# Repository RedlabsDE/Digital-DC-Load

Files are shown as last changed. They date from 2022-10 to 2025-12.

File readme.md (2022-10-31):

# Digtial DC Load Project

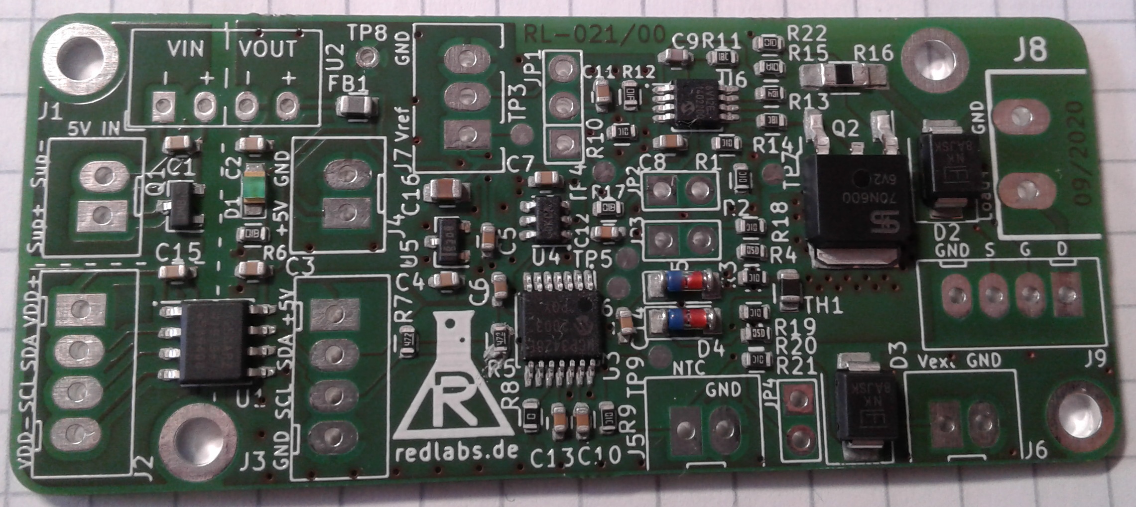
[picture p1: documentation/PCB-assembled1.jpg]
PCB assembled


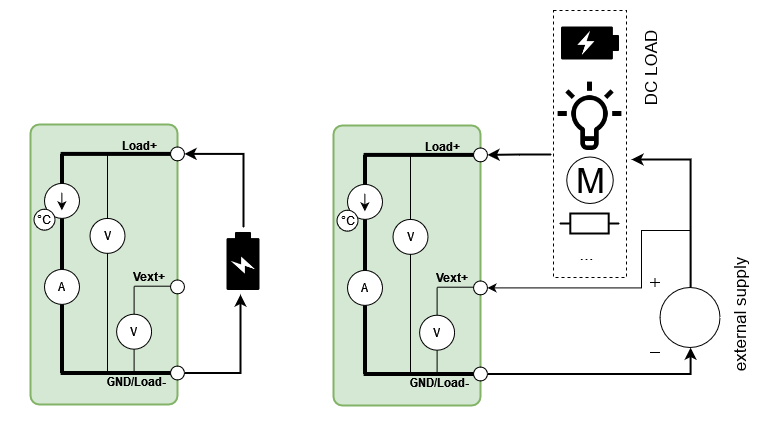
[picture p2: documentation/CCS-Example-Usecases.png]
Blockdiagram of example usecases Example Usecases


**key features:**
- linear constant curren sink
- galvanic isolated
- selectable operating range (high/low current/voltage)
- controlled via I2C
	- write & read load current
	- read load voltage
	- read additional external voltage
	- read temperature 
- manual option: set current via external voltage (or potentiometer)

**example application:**
- charge / discharge battery (control & measure current and voltage)
- measure & log current/voltage (use example setup to send data to PC)
- stess test of power supply

## Repository Overview
- **documentation**
  - application notes for constant current sink 
  - block diagram of PCB
  - screenshots and pictures of this project
- **firmware**
  - Arduino Example Project `DigitalLoadExample`, inlcuding a C++ class `RL021_DigitalLoad` for easy control
  - Example calibration procedure (manually step by step)
- **hardware**
  - **KiCAD** Project Folder including schematic, PCB layout and BOM
  - **schematic** and fabrication layer drawing as PDF
  - **datasheet** of used components
- **ui**
  - **GUI_CSS** is an example project for a simple pc-based user interface (written in processing)

## Hardware
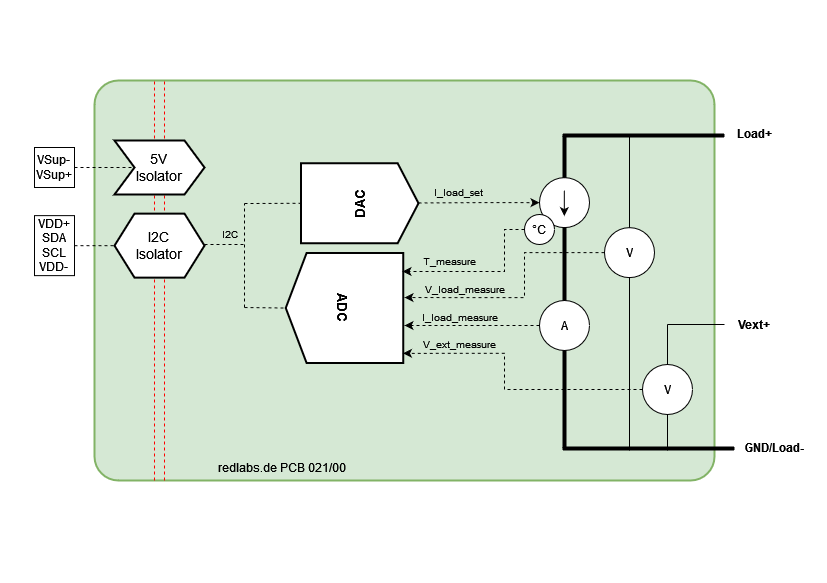
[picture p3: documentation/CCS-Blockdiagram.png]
Blockdiagram of PCB Blockdiagram

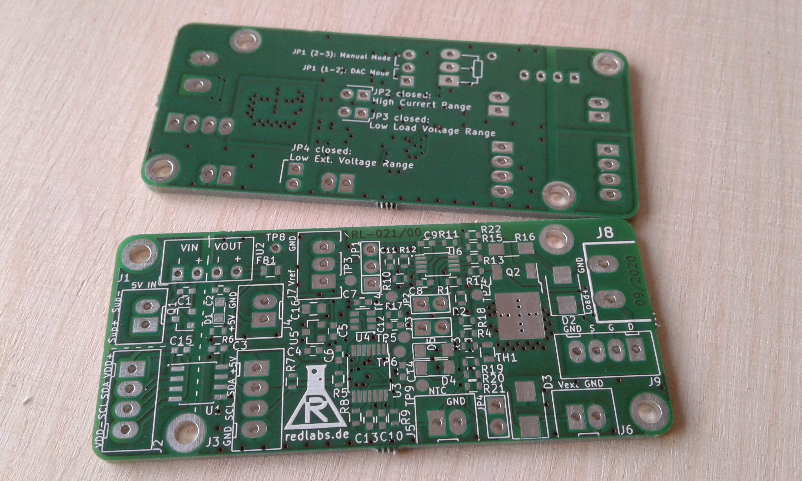
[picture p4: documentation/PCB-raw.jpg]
PCB not assembled


**Order PCB:** https://aisler.net/p/YHESFYKF

### Jumper Settings
Via multiple jumpers the used operating ranges can be configured.

| Parameter | Jumper | open | closed |
| -- | -- | -- | -- |
| Current Control | JP1 | External analog signal | Digital via onboard DAC |
| I_load range | JP2 | low 0-1A | high 0-10A |
| V_load range | JP3 | high 0-24V | 0-4V |
| V_extern range | JP4 | high 0-24V | 0-4V |
| ADC I2C Addr (A2,A1,A0)| R8 | 0,0,1 | 0,0,0 |

# Example Setup
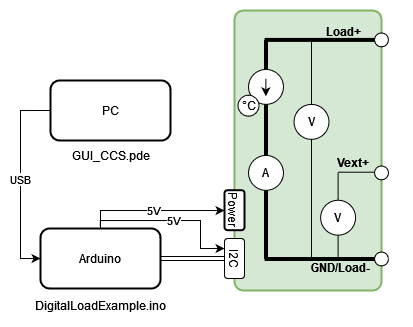
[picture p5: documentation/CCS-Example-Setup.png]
Blockdiagram of example setup Example Setup


## Example Arduino Control

### Connect Arduino to CCS-PCB
| Signal 	| Arduino Pin |
|---|---|
| I2C_VDD (J2, pin1) 	| 5V 	|
| I2C_SDA (J2, pin2) 		| A4 |
| I2C_SCL (J2, pin3) 	| A5 	|
| I2C_GND (J2, pin4) 	| GND 	|
| SUPPLY_+5V (J1, pin1) 	| 5V 	|
| SUPPLY_GND (J1, pin2) 	| GND 	|

### Configure CCS-PCB according to your application
- See chapter "Jumper Settings" to select your operating range
- In the Arduino Code, the settings should be set according to physical state of the jumpers:
	```
		/// Write board jumper settings (like set on PCB)
		myLoad.SetJumperSetting(JP2_CURRENT,Jumper_Closed);
		myLoad.SetJumperSetting(JP3_VLOAD,Jumper_Open);
		myLoad.SetJumperSetting(JP4_VEXT,Jumper_Open);  
	```

## Example User Interface
An example PC-based user interface (written in "Processing"), for the use with the `firmware/DigitalLoadExample` project.

### Connect UI to Arduino ###
- The UI communicates via serial comport using simple ASCII character commands, so the communication could also be done manual.  
- The UI uses the first found COMPORT (to use another port, change this in the processing code)
	````
	  String portName = Serial.list()[0];
	  myPort = new Serial(this, portName, 115200);
	````
### Usage ###
In the "Control" page, all measured values are displayed in SI-units. The user can set the desired load current in mA.
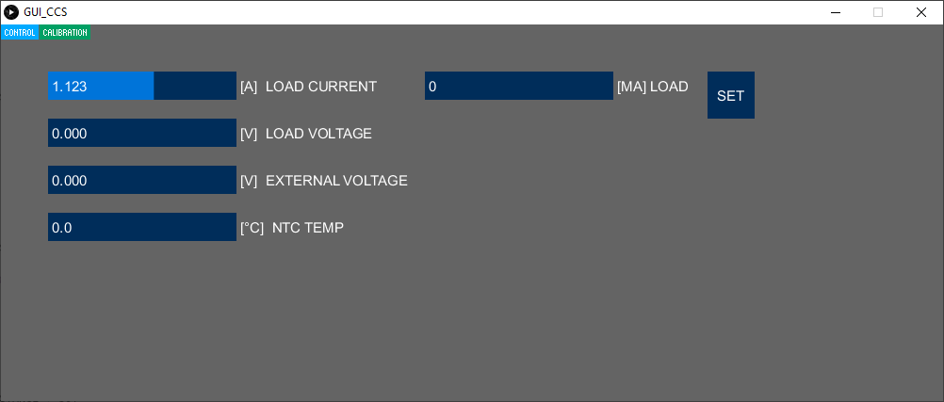
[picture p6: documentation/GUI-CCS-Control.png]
GUI Control


In the "Calibration" page, the raw ADC values are displayed. The user can set the raw DAC value.
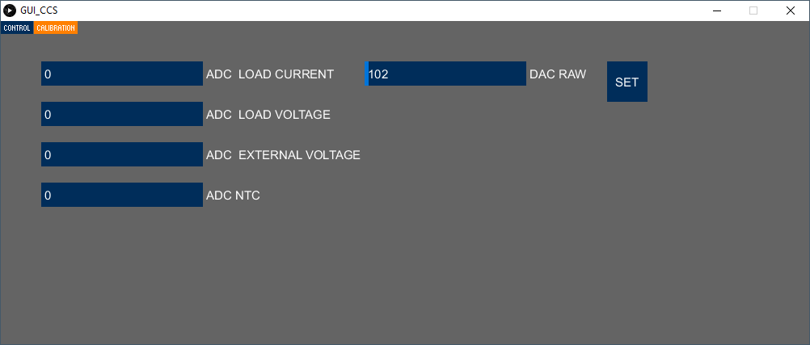
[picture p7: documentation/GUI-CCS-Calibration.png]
GUI Control GUI Calibration


... find other projects: https://redlabs.de/

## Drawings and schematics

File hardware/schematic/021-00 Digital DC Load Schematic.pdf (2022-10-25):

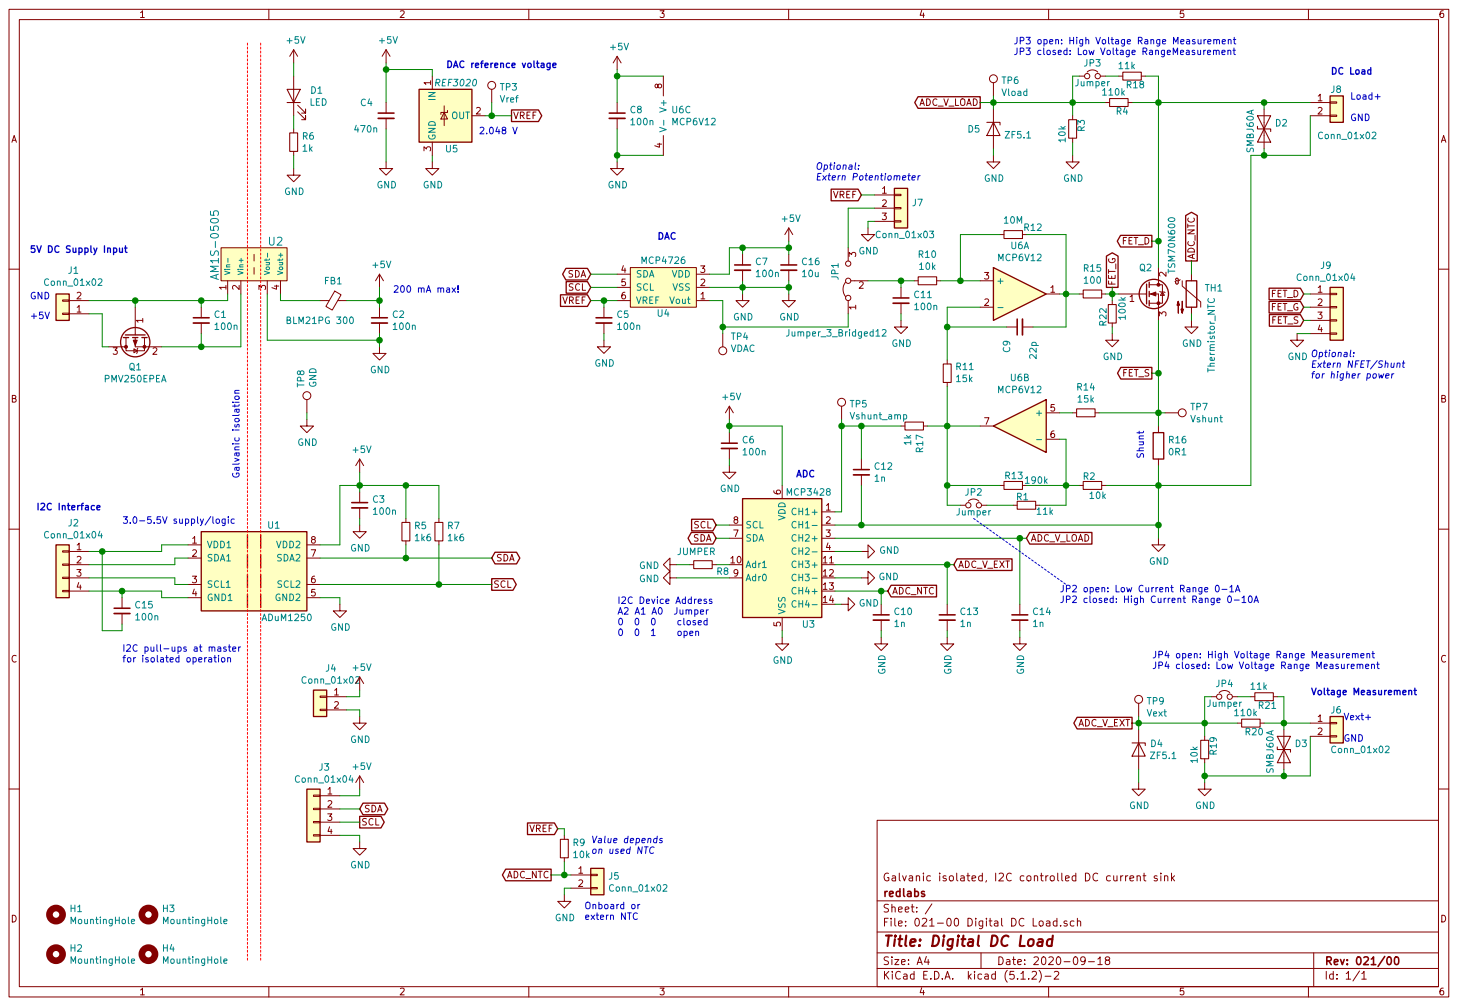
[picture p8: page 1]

JP3 open: High Voltage Range Measurement
JP3 closed: Low Voltage RangeMeasurement
VREF Optional: Extern Potentiometer GND

Optional: Extern NFET/Shunt

JP2 open: Low Current Range 0-1A
1n GND

I2C Device Address A2 A1 A0 Jumper 0 0 0 closed

I2C pull-ups at master
for isolated operation

JP4 open: High Voltage Range Measurement
JP4 closed: Low Voltage Range Measurement
Jumper GND

Value depends on used NTC

Id: 1/1 Title: Digital DC Load

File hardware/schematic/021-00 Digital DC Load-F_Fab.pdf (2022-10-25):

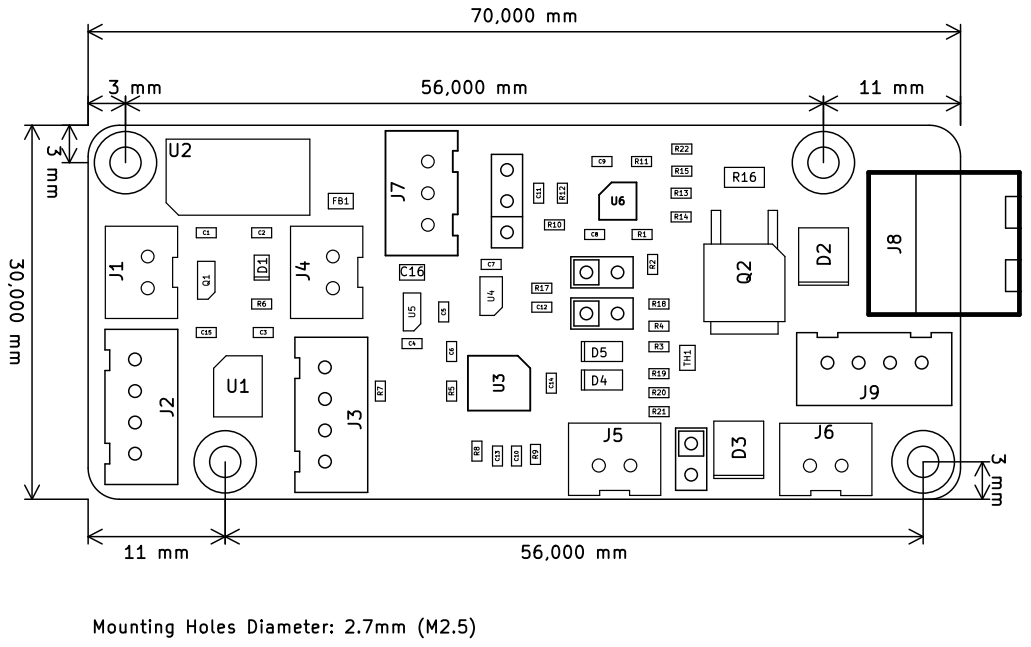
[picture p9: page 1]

File: 021-00 Digital DC Load.kicad_pcb Sheet:
Id: 1/1 Title:

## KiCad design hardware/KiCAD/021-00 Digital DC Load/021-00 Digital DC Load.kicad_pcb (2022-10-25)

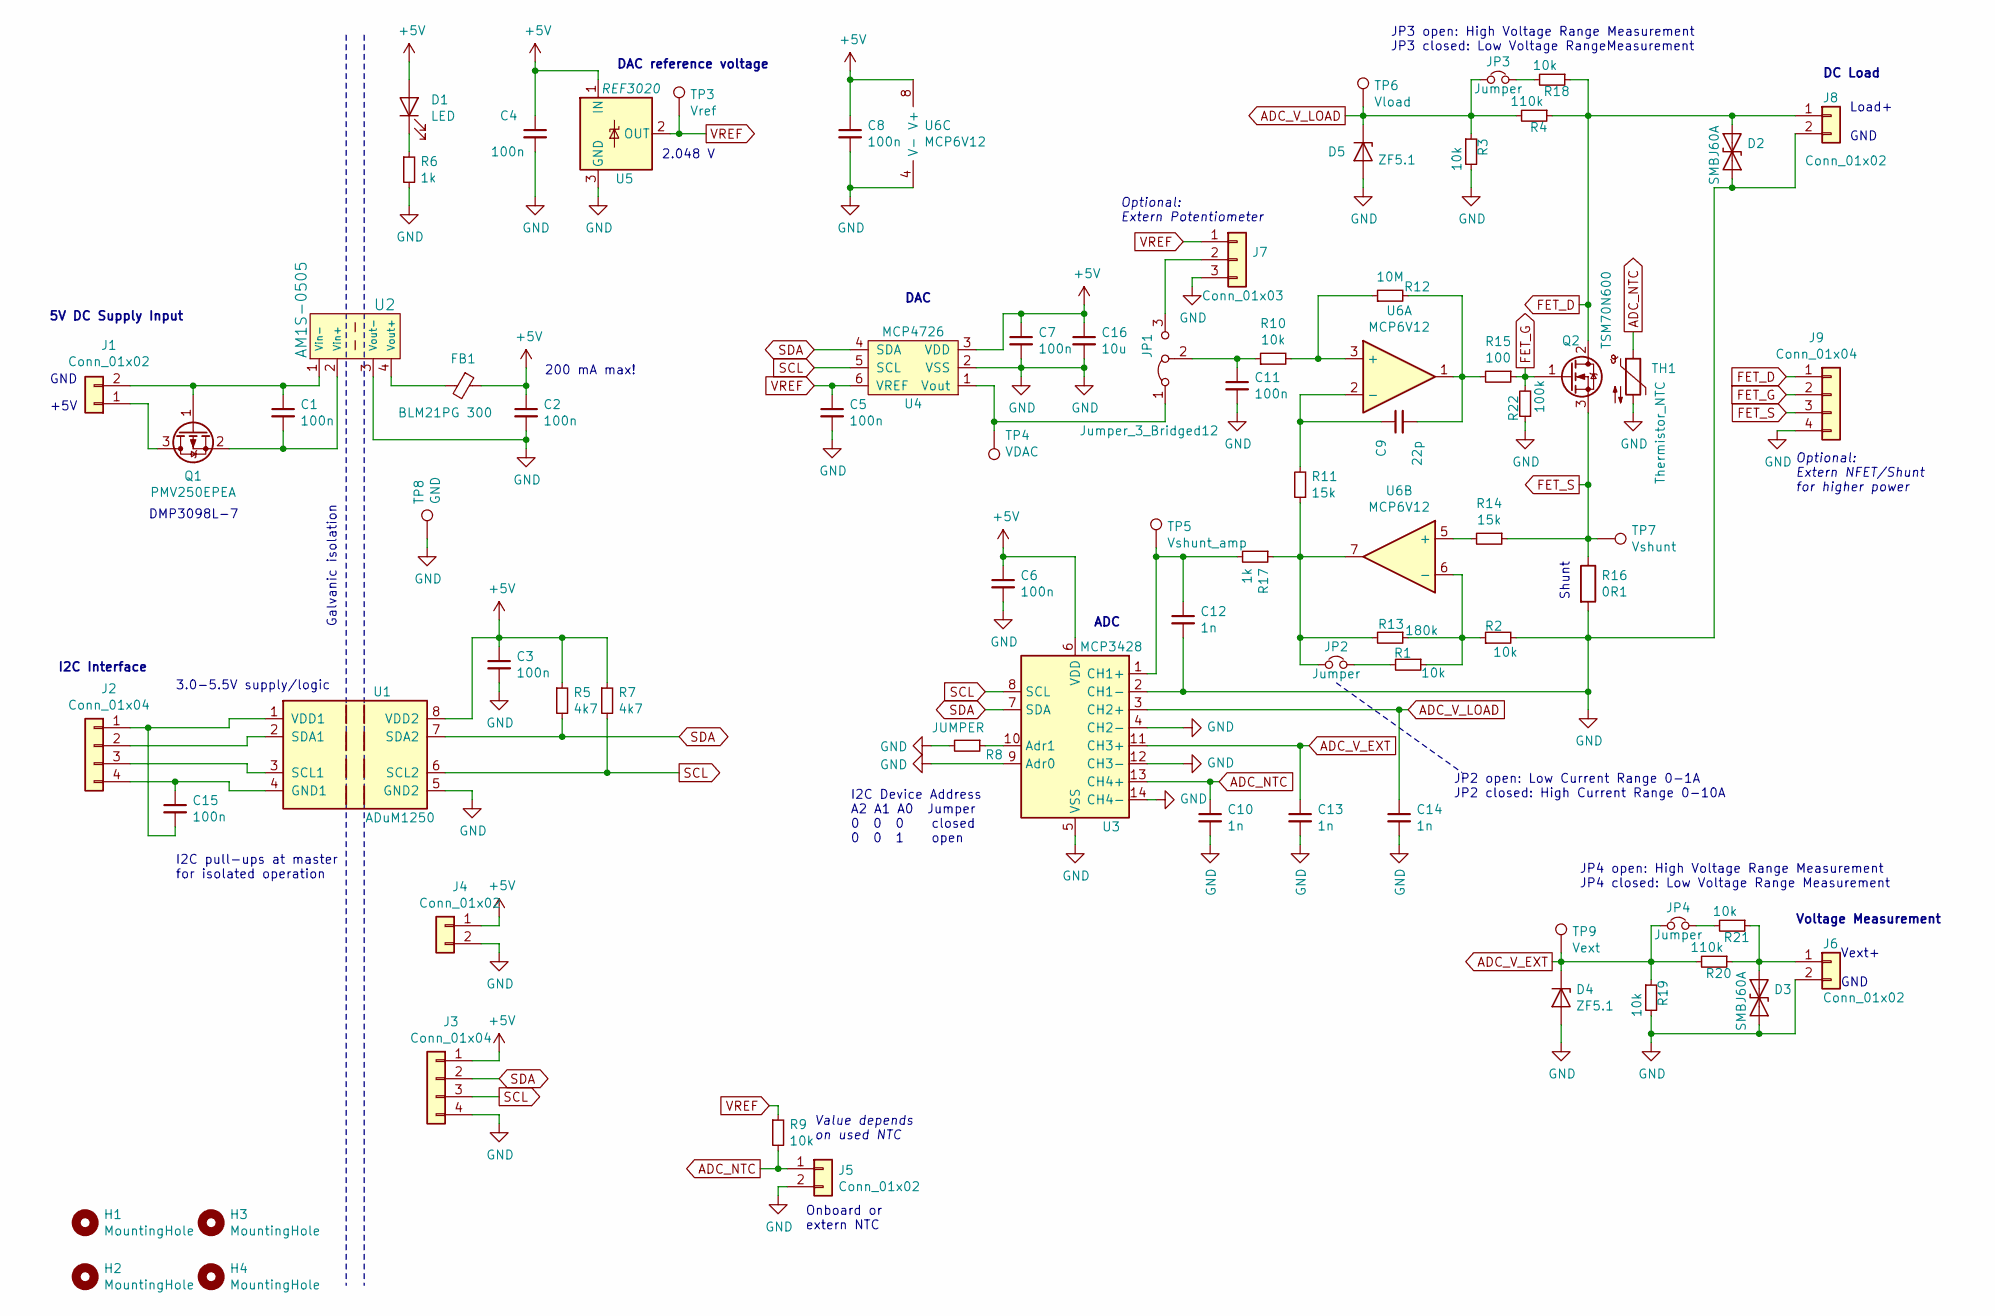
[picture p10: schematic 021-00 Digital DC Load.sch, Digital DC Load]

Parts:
C1, C2, C3, C4, C5, C6, C7, C8, C11, C15: 100n; C_0603
C9: 22p; C_0603
C10, C12, C13, C14: 1n; C_0603
C16: 10u; C_0805
D1: LED; LED_0805
D2, D3: SMBJ60A; D_SMB_bidirectional
D4, D5: ZF5.1; D_MiniMELF
FB1: BLM21PG 300; R_0805
H1, H2, H3, H4: MountingHole; MountingHole_2.7mm_M2.5_DIN965_Pad
J1, J4, J5, J6: Conn_01x02; JST_XH2P_oval_pads
J2, J3, J9: Conn_01x04; JST_XH4P_oval_pads
J7: Conn_01x03; JST_XH3P_oval_pads
J8: Conn_01x02; AKL_2_RM508_RND205-00199
JP1: Jumper_3_Bridged12; PIN_ARRAY_3X1_big_pads
JP2, JP3, JP4: Jumper; PIN_ARRAY_2X1_big_pads
Q1: PMV250EPEA; SOT-23
Q2: TSM70N600; TO-252-2
R1, R2, R3, R9, R10, R18, R19, R21: 10k; R_0603
R4, R20: 110k; R_0603
R5, R7: 4k7; R_0603
R6, R17: 1k; R_0603
R8: JUMPER; R_0603
R11, R14: 15k; R_0603
R12: 10M; R_0603
R13: 180k; R_0603
R15: 100; R_0603
R16: 0R1; R_1206_HandSoldering
R22: 100k; R_0603
TH1: Thermistor_NTC; R_0805
TP3: Vref; Measurement_Point_Round-SMD-Pad_Small
TP4: VDAC; Measurement_Point_Round-SMD-Pad_Small
TP5: Vshunt_amp; Measurement_Point_Round-SMD-Pad_Small
TP6: Vload; Measurement_Point_Round-SMD-Pad_Small
TP7: Vshunt; Measurement_Point_Round-SMD-Pad_Small
TP8: GND; Measurement_Point_Round-TH_Small
TP9: Vext; Measurement_Point_Round-SMD-Pad_Small
U1: ADuM1250; SOIC-8_3.9x4.9mm_Pitch1.27mm
U2: AM1S-0505; DCDC-Isolated-SIP4
U3: MCP3428; TSSOP-14_4.4x5mm_Pitch0.65mm
U4: MCP4726; SOT-23-6
U5: REF3020; SOT-23
U6: MCP6V12; MSOP-8_3x3mm_Pitch0.65mm

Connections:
+5V: C2.1, C3.1, C4.1, C6.1, C7.1, C8.1, C16.1, D1.2 (A), FB1.1, J3.1, J4.1, R5.1, R7.1, U1.8 (VDD2), U3.6 (VDD), U4.3 (VDD), U5.1 (IN), U6.8 (V+)
ADC_NTC: C10.1, J5.1, R9.2, TH1.1, U3.13 (CH4+)
ADC_V_EXT: C13.1, D4.1 (K), JP4.1, R19.1, R20.2, TP9.1, U3.11 (CH3+)
ADC_V_LOAD: C14.1, D5.1 (K), JP3.1, R3.1, R4.2, TP6.1, U3.3 (CH2+)
FET_D: D2.1 (A1), J8.1, J9.1, Q2.2 (D), R4.1, R18.1
FET_G: J9.2, Q2.1 (G), R15.1, R22.2
FET_S: J9.3, Q2.3 (S), R14.1, R16.1, TP7.1
GND: C2.2, C3.2, C4.2, C5.2, C6.2, C7.2, C8.2, C10.2, C11.2, C12.2, C13.2, C14.2, C16.2, D2.2 (A2), D3.2 (A2), D4.2 (A), D5.2 (A), J3.4, J4.2, J5.2, J6.2, J7.3, J8.2, J9.4, R2.2, R3.2, R6.2, R8.2, R16.2, R19.2, R22.1, TH1.2, TP8.1, U1.5 (GND2), U2.3 (Vout-), U3.2 (CH1-), U3.4 (CH2-), U3.5 (VSS), U3.9 (Adr0), U3.12 (CH3-), U3.14 (CH4-), U4.2 (VSS), U5.3 (GND), U6.4 (V-)
unnamed: C1.1, J1.2, Q1.1 (G), U2.1 (Vin-)
unnamed: C1.2, Q1.2 (S), U2.2 (Vin+)
unnamed: C9.1, R11.2, U6.2 (-)
unnamed: C9.2, R12.2, R15.2, U6.1
unnamed: C11.1, JP1.2 (C), R10.1
unnamed: C12.1, R17.2, TP5.1, U3.1 (CH1+)
unnamed: C15.1, J2.4, U1.4 (GND1)
unnamed: C15.2, J2.1, U1.1 (VDD1)
unnamed: D1.1 (K), R6.1
unnamed: D3.1 (A1), J6.1, R20.1, R21.1
unnamed: FB1.2, U2.4 (Vout+)
unnamed: J1.1, Q1.3 (D)
unnamed: J2.2, U1.2 (SDA1)
unnamed: J2.3, U1.3 (SCL1)
unnamed: J7.2, JP1.3 (B)
unnamed: JP1.1 (A), TP4.1, U4.1 (Vout)
unnamed: JP2.1, R11.1, R13.2, R17.1, U6.7
unnamed: JP2.2, R1.2
unnamed: JP3.2, R18.2
unnamed: JP4.2, R21.2
unnamed: R1.1, R2.1, R13.1, U6.6 (-)
unnamed: R8.1, U3.10 (Adr1)
unnamed: R10.2, R12.1, U6.3 (+)
unnamed: R14.2, U6.5 (+)
SCL: J3.3, R7.2, U1.6 (SCL2), U3.8 (SCL), U4.5 (SCL)
SDA: J3.2, R5.2, U1.7 (SDA2), U3.7 (SDA), U4.4 (SDA)
VREF: C5.1, J7.1, R9.1, TP3.1, U4.6 (VREF), U5.2 (OUT)

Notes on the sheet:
2.048 V
I2C Device Address A2 A1 A0 Jumper 0 0 0 closed 0 0 1 open
Shunt
Optional: Extern Potentiometer
Onboard or extern NTC
5V DC Supply Input
I2C Interface
3.0-5.5V supply/logic
I2C pull-ups at master for isolated operation
+5V
GND
200 mA max!
Optional: Extern NFET/Shunt for higher power
Galvanic isolation
DC Load
Value depends on used NTC
DAC
ADC
DAC reference voltage
Load+ GND
Voltage Measurement
Vext+ GND
JP4 open: High Voltage Range Measurement JP4 closed: Low Voltage Range Measurement
JP3 open: High Voltage Range Measurement JP3 closed: Low Voltage RangeMeasurement
JP2 open: Low Current Range 0-1A JP2 closed: High Current Range 0-10A
DMP3098L-7

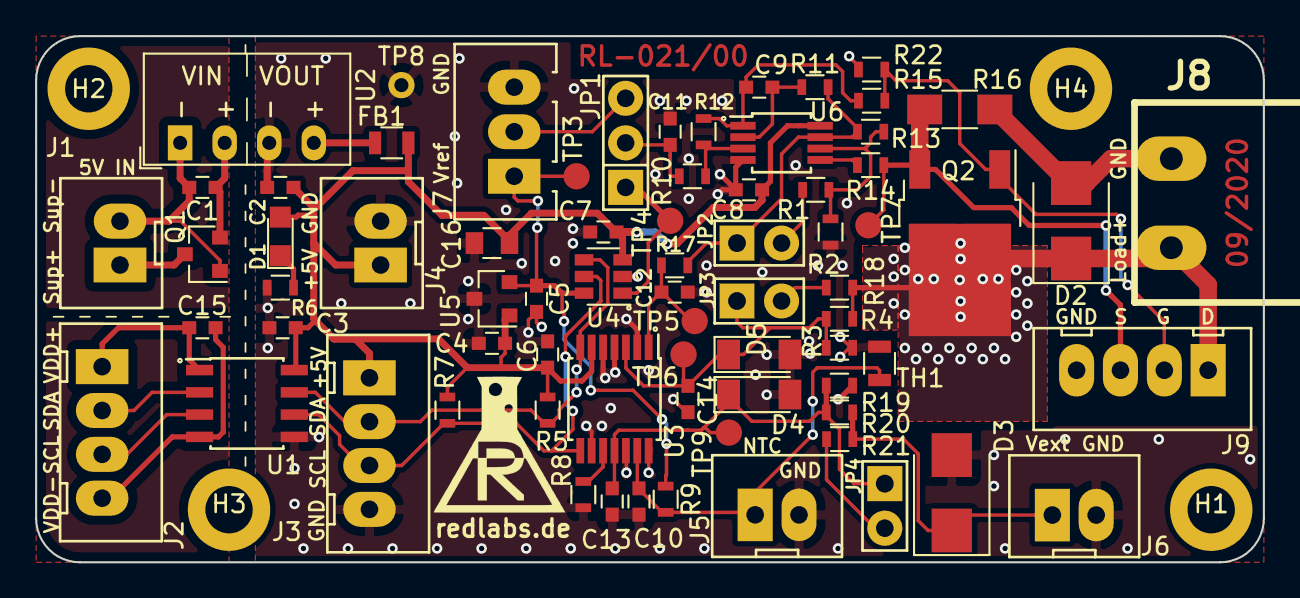
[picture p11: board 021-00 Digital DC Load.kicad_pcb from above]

Board: 2 copper layers, 70.0 x 30.0 mm, 77 parts (0 on the bottom side), 35 nets.

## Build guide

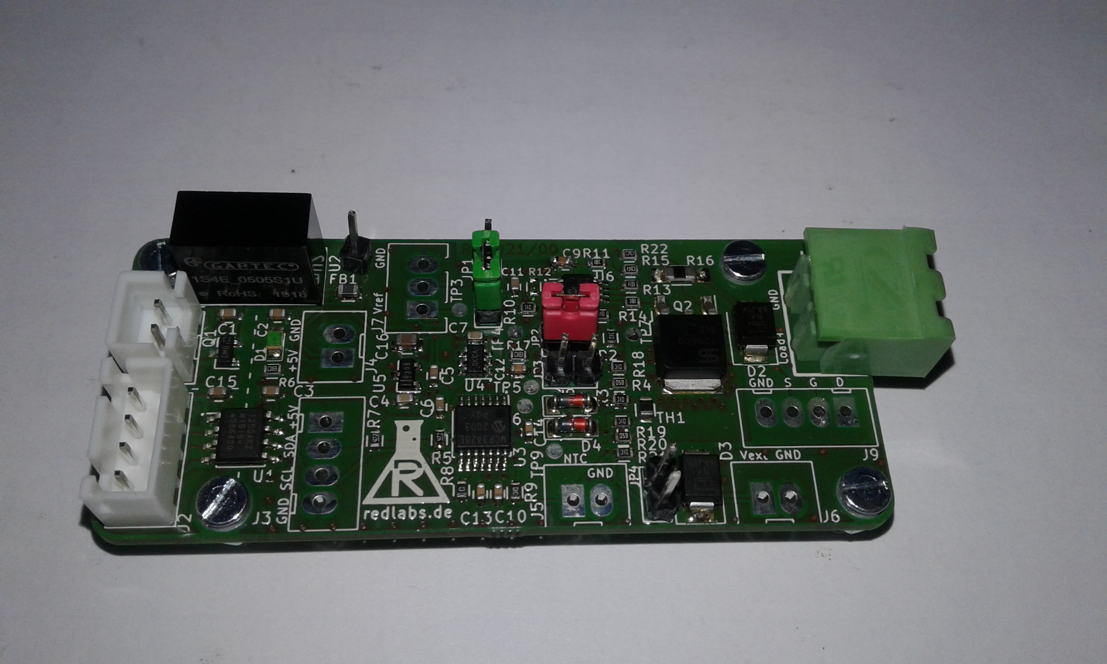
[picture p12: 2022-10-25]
documentation/PCB-assembled2.jpg

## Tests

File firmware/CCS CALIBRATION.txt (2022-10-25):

Step-by-step manual calibration of Voltage/Current Measurement and Current setting

-------------------------------------
VLOAD
-------------------------------------
Manually apply external voltage to VLOAD (here: 10V and 20V) and read back ADC values:

//Measurement #1
V1= 	10000 mV
ADC1= 	13254	

//Measurement #2
V2= 	20000 mV
ADC2= 	26516	

-------------------------------------
Calaculate slope and offset of voltage measurement, using measurement results:

slope = (V2-V1)/(ADC2-ADC1)
offset = V1 - slope*ADC1
slope = (20000mV-10000mV)/(26516 - 13254) = 10000.0/13262  = 0.75403
offset = V1 - [ (10000.0/13262) * 13254 ] = 4

-------------------------------------
ILOAD: (C9:3n3, JP2 closed)
-------------------------------------
Manually set DAC in GUI "Calibration" page and manually measure the current with multimeter (here: 100mA and 500mA), write down set DAC value and read back ADC values:

//Measurement #1
I1=	100mA
DAC1=	46
ADC1=	320

//Measurement #2
I2=	500mA
DAC2=	211
ADC2=	1638

-------------------------------------
Calaculate slope and offset of current control, using measurement results:
slope = (I2-I1)/(DAC2-DAC1)
offset = I1 - slope*DAC1

slopeDAC = (500-100)/(211-46) =  400/165 = 2.42
offsetDAC = 100 - (2.42)*46 = -11,5

-------------------------------------
Calaculate slope and offset of current measurement, using measurement results:
slope = (I2-I1)/(ADC2-ADC1)
offset = I1 - slope*ADC1

slopeADC = (500-100)/(1638-320) = 400/1318 = 0.303
offsetADC = 100 - (0.303)*320 = 3

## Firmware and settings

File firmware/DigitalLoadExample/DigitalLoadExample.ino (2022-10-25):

/**
* \file    DigitalLoadExample.ino
* \brief    Example Control of Digital Constant Current Source
* \brief    Required hardware: PCB RL-021/xx, Microcontroller (Arduino) with I2C communication  
* \brief    Required drivers: MCP47x6.h, MCP3428.h
* 
* \brief    basic functions: 
*               -Set constant load current and read back all measured channels
                -Control via serial commands
                -Output waveforms to load
* 
* \author  Julian Schindler
*
* \par     Editor 
*
* \date    20.09.2020 first implementation
*
* \todo
* \version V0.1
*/



/*
 * Arduino Nano
 * 
 * I2C - SDA: A4
 * I2C - SCL: A5
 */

#include "printf.h"

#include "RL021_DigitalLoad.h"

////////////////////////////////////////////////////////////////////////////////////
#ifndef MOCK_ADC_DAC
  /// Create DAC Object with default I2C adress 0x60
  MCP47x6base * DAC_mcp47x6 = new MCP4726;
  //MOCK_MCP47x6base DAC_mcp47x6;
  
  /// Create ADC Object with default I2C adress 0x68
  MCP3428 ADC_mcp3428(0); /// A2, A1, A0 bits (000, 0x68)
  //MOCK_MCP3428 ADC_mcp3428; /// debug
  
  /// Create DigitalLoad Object
  //RL021_DigitalLoad myLoad(DAC_mcp47x6, &ADC_mcp3428);
  
  /// Create DigitalLoad Object with mocked ADC/DAC
  RL021_DigitalLoad myLoad(DAC_mcp47x6,&ADC_mcp3428);
////////////////////////////////////////////////////////////////////////////////////
#else

  //Use simulation of ADC and DAC if required hardware is not present
  MCP47x6base DAC_mcp47x6;
  MCP3428 ADC_mcp3428;
  RL021_DigitalLoad myLoad(&DAC_mcp47x6,&ADC_mcp3428);

#endif
////////////////////////////////////////////////////////////////////////////////////
int countTicks = 10000;
uint16_t currentToSet;

/// Increment current stepwise by 1 LSB of DAC (via serial command '+'/'-')
void calibrateCurrent();

/// Print raw ADC data for all 4 channels
void calibrateVoltage();

/// Send all ADC measured values via serial port
void sendInfo();
void sendInfoProtocol();
void sendRawInfoProtocol();

// send 'r' to switch to raw data
// send 't' to switch to mA/mV data
bool sendRawInfo = false; //(false): sendInfoProtocol(), (true):sendRawInfoProtocol()

/// Dummy output functions (call frequently to get waveform)
void Sawtooth();
void Triangle();
void Square(uint16_t currentLevel);

void setup() {
  
  while (!Serial);
  Serial.begin(115200);
  printf_begin();

  //Serial.println("<RL 021/00 Digital Load>");
/*
  Serial.print("check for DAC ... ");
    if (!DAC_mcp47x6->devicepresent()) 
    {
      Serial.println("DAC Device not found");
    }
    else
    {
      Serial.println("DAC Device OK");
    }

    /// Use external voltage reference (2.048V onboard) 
    DAC_mcp47x6->setReference(MCP47x6base::refpinbuff);

    Serial.print("check for ADC ... ");
    if (!ADC_mcp3428.testConnection()) 
    {
      Serial.println("ADC Device not found");
    }
    else
    {
      Serial.println("ADC Device OK");
    }
    */

    DAC_mcp47x6->setReference(MCP47x6base::refpinbuff);


    /// Write board jumper settings (like set on PCB)
    myLoad.SetJumperSetting(JP2_CURRENT,Jumper_Closed);
    myLoad.SetJumperSetting(JP3_VLOAD,Jumper_Open);
    myLoad.SetJumperSetting(JP4_VEXT,Jumper_Open);  

    /// Write calibration data, otherwise default calibration is used
    ///...
    
    currentToSet = 0;
    myLoad.SetCurrent_mA(currentToSet);

    //Serial.println("<start loop>");

}

void loop() 
{  

  //Sawtooth(200);
  //Triangle(150);
  //Square(133);
  //myLoad.SetCurrent_mA(currentToSet);

  /*
  Serial.print("c: ");
  Serial.print(currentToSet);
  Serial.println();
  */
  
  //calibrateCurrent();

  //calibrateVoltage();

  //Character received via UART
  if ( Serial.available() )
  {
    handleSerialCommand();
  }
  
  //tick counter
  countTicks++;
  if (countTicks > 100) //1s
  {
    countTicks = 0;
    //sendInfo();
    

    if(sendRawInfo)
    {
      sendRawInfoProtocol();
    }
    else
    {
      sendInfoProtocol();
    }
  }
  
  delay(10);
}

//////////////////////////////////////////////////////////////////////////////////////////////////////////////////////////////////////////////////////////
// Read and Interprete Serial command from PC
//////////////////////////////////////////////////////////////////////////////////////////////////////////////////////////////////////////////////////////


///////////////////////////////////////////////////////////////////////////
/*
Single character commands:
'+' Increment DAC +1
'-' Decrement DAC -1
'0' Set DAC to 0
'8' Increment DAC +100
'2' Decrement DAC -100
'r' set sendRawInfo TRUE
't' set sendRawInfo FALSE

Multi character commands:
'sa' Read ASCII digits (1-9999) 'e' set load current in mA
'sf' Read ASCII digits (1-9999) 'e' set raw DAC value

'<' Ignore following characters until '>' received



*/
void handleSerialCommand()
{
  uint16_t serialNumber = 0;
                            // E, Z, H, T, ZT
  static uint8_t number[5] = {0,0,0,0,0};
  static bool readInDigit = false;
  static bool firstCharacter = false;
  static uint8_t serialDigitType = 0;
  
  /// Read single character via serial port
  char c = (Serial.read());

  /// Check for multi character command start sign
  if(c == 's' && readInDigit == false)
  {
    readInDigit = true;
    firstCharacter = true;  
  }
  else if(firstCharacter == true)
  {
    serialDigitType = c;
    readInDigit = true;
    firstCharacter = false;
  }
  /// Check for multi character commands data
  if(readInDigit)
  {
      if(c >= 48 && c <= 57)//ASCII '0'-'9'
      {
        uint8_t newDigit;  
        newDigit = c - 48; //ASCII '0'-'9' to integer
        number[4] = number[3]; //ZT
        number[3] = number[2]; //T
        number[2] = number[1]; //H
        number[1] = number[0]; //Z
        number[0] = newDigit; //E      
      }    
  }

  /// Single character commands
  if(readInDigit == false)
  {
      switch (c)
      {
        case '+': //increment DAC small step
            DAC_IncrementRaw(1, 0, 0);
          break;
        case '-': //decrement DAC small step
            DAC_IncrementRaw(0, 0, 0);
          break;
        case '0': //set DAC to 0
            DAC_IncrementRaw(0, 0, 1);
          break;
        case '8': ///increment DAC big step
            DAC_IncrementRaw(1, 1, 0);
          break;
        case '2': //decrement DAC bif step
            DAC_IncrementRaw(0, 1, 0);
          break;
        case 'r':
              sendRawInfo = true;
          break;
        case 't':
              sendRawInfo = false;
          break;
        case '5':
          
          break;
        case '6':
          
          break;
        case '7':
          
          break;
        case '9':
          break;
        default:
          Serial.println("single command unknown");
          break;
      }
  }

  /// Check for multi character command end sign
  if(c == 'e' && readInDigit == true)
  {
    serialNumber = number[0] + number[1]*10 + number[2]*100 + number[3]*1000 + number[4]*10000;
    number[4] = 0;
    number[3] = 0;
    number[2] = 0;
    number[1] = 0;
    number[0] = 0;

    if(serialDigitType == 'a')
    {
      //set read in number to DAC
      myLoad.SetCurrent_mA(serialNumber);   
      Serial.print("<");
      Serial.print("Set Load Current [mA]: ");
      Serial.print(serialNumber);
      Serial.print(">");
      Serial.println();
    }
    else if (serialDigitType == 'f')
    {
      myLoad.SetRawDac(serialNumber);
      Serial.print("<");
      Serial.print("raw DAC set: ");
      Serial.print(serialNumber);
      Serial.print(">");
      Serial.println();
    }


    readInDigit = false;
  }


}


/** Quick & Dirty function to increment/decrement DAC counts
 *
 *  @param bool increment - (1): Increment,   (0): Decrement
 *  @param bool bigStep -   (1): step = 100   (0): step = 1
 *  @param bool reset -     (1): set DAC to 0 (0): Increment/Decrement
 *  @return /
 */
void DAC_IncrementRaw(bool increment, bool bigStep, bool reset)
{
  static uint16_t dacCounts = 0;
  
  if(reset)
  {
    dacCounts = 0;
  }
  else
  {
    if(increment)
    {
      dacCounts += 1 + bigStep*99;     
    }
    else
    {
        dacCounts -= 1 + bigStep*99;
    }
  }

  // Check DAC range
  if(dacCounts > 4095)
  {
    if(increment)
    {
      dacCounts = 4095;
    }
    else
    {
      dacCounts = 0;
    }
  } 
  
  //DAC_mcp47x6->setVOut(dacCounts);
  myLoad.SetRawDac(dacCounts);
  /*
  Serial.print("DAC counts: ");
  Serial.print(dacCounts);
  Serial.println();
  */
}

///////////////////////////////////////////////////////////////////////////
// Set raw DAC value via serial commands
/*
 * '0'  set DAC count to 0
 * '+'  increment DAC counts by 1 (set to 0 if > 4095)
 * '-'  decrement DAC counts by 1 (set to 4095 if < 0)
 * '8'  increment DAC counts by 100
 */
void calibrateCurrent()
{
  static uint16_t dacCounts = 0;
  
  //Character received via UART
  if ( Serial.available() )
  {
      char c = (Serial.read());
    
          switch (c)
          {
            case '0':
              dacCounts = 0;
              break;
            case '+':
              dacCounts++;
              break;
            case '-':
              if(dacCounts)
              {
                dacCounts--;
              }
              else
              {
                 dacCounts = 4095;             
              }
              break;
             case '8':
              dacCounts += 100;
              break;
             default:
             break;
          }
      
      if(dacCounts > 4095)
      {
        dacCounts = 0;
      }   

      myLoad.SetRawDac(dacCounts);
      Serial.print("DAC counts: ");
      Serial.print(dacCounts);
      Serial.println();
  }
}


///////////////////////////////////////////////////////////////////////////
// Measure all ADC channels and print raw values
void calibrateVoltage()
{
  int16_t rawAdc = 0;

  rawAdc = myLoad.GetRawAdc(ADC_CH_CURRENT);
  Serial.print("ADC counts current: ");
  Serial.print(rawAdc);
  Serial.println();

  rawAdc = myLoad.GetRawAdc(ADC_CH_VLOAD);
  Serial.print("ADC counts Vload: ");
  Serial.print(rawAdc);
  Serial.println();

  rawAdc = myLoad.GetRawAdc(ADC_CH_VEXT);
  Serial.print("ADC counts Vext: ");
  Serial.print(rawAdc);
  Serial.println();

  rawAdc = myLoad.GetRawAdc(ADC_CH_NTC);
  Serial.print("ADC counts NTC: ");
  Serial.print(rawAdc);
  Serial.println();  

}

//////////////////////////////////////////////////////////////////////////////////////////////////////////////////////////////////////////////////////////
// Quick&Dirty DAC Waveforms - call frequently to get the waveform
//////////////////////////////////////////////////////////////////////////////////////////////////////////////////////////////////////////////////////////

///////////////////////////////////////////////////////////////////////////
// Increment until currentLevel is reached, start again at 0
void Sawtooth(uint16_t currentLevel)
{
  currentToSet++;

  if(currentToSet > currentLevel)
  {
    currentToSet = 0;
  }  
}

///////////////////////////////////////////////////////////////////////////
// Increment until currentLevel is reached, decrement until 0 is reached, start again
void Triangle(uint16_t currentLevel)
{
  static bool increment = true;

  if(increment)
  {
    currentToSet++;
  }
  else
  {
    currentToSet--;
  }
  
  if(currentToSet > currentLevel)
  {
    increment = false;
  }  
  
  if(currentToSet == 0)
  {
    increment = true;
  }
}

///////////////////////////////////////////////////////////////////////////
// Toggle between 0 and currentLevel, time is hard coded to duration
void Square(uint16_t currentLevel)
{
  static bool out = true;
  static uint8_t duration = 50;

  duration--;

  if(duration == 0)
  {
    duration = 50;

    if(out)
    {
      currentToSet = currentLevel;
    }
    else
    {
      currentToSet = 0;      
    }
    out = !out;  
  }  
}

//////////////////////////////////////////////////////////////////////////////////////////////////////////////////////////////////////////////////////////
// Print Info
//////////////////////////////////////////////////////////////////////////////////////////////////////////////////////////////////////////////////////////

///////////////////////////////////////////////////////////////////////////
/// Send values in SI units
/*
 * 's'a'...'e'  load current in mA
 * 's'b'...'e'  load voltage in mV
 * 's'c'...'e'  extern voltage in mV
 * 's'd'...'e'  NTC temp in °Cx10
 */
void sendInfoProtocol()
{
  Serial.print("sa");
  Serial.print(myLoad.GetCurrent_mA());
  Serial.print("e");
  Serial.println();

  Serial.print("sb");
  Serial.print(myLoad.GetVoltageLoad_mV());
  Serial.print("e");
  Serial.println();

  Serial.print("sc");
  Serial.print(myLoad.GetVoltageExt_mV());
  Serial.print("e");
  Serial.println();

  Serial.print("sd");
  Serial.print(myLoad.GetTemperature());
  Serial.print("e");
  Serial.println();   
}

///////////////////////////////////////////////////////////////////////////
/// Send raw ADC values
/*
 * 's'f'...'e'  load current channel
 * 's'g'...'e'  load voltage channel
 * 's'h'...'e'  extern voltage channel
 * 's'i'...'e'  NTC temp channel
 */
void sendRawInfoProtocol()
{
  //////////
  Serial.print("sf");
  Serial.print(myLoad.GetRawAdc(ADC_CH_CURRENT));
  Serial.print("e");
  Serial.println();

  Serial.print("sg");
  Serial.print(myLoad.GetRawAdc(ADC_CH_VLOAD));
  Serial.print("e");
  Serial.println();

  Serial.print("sh");
  Serial.print(myLoad.GetRawAdc(ADC_CH_VEXT));
  Serial.print("e");
  Serial.println();

  Serial.print("si");
  Serial.print(myLoad.GetRawAdc(ADC_CH_NTC));
  Serial.print("e");
  Serial.println();  
}


///////////////////////////////////////////////////////////////////////////
/// Send readable info to console
void sendInfo()
{
  Serial.print("ADC: current [mA]: ");
  Serial.print(myLoad.GetCurrent_mA());
  Serial.println();

  Serial.print("ADC: load voltage [mV]: ");
  Serial.print(myLoad.GetVoltageLoad_mV());
  Serial.println();

  Serial.print("ADC: ext voltage [mV]: ");
  Serial.print(myLoad.GetVoltageExt_mV());
  Serial.println();

  Serial.print("ADC: NTC temp [C x10]: ");
  Serial.print(myLoad.GetTemperature());
  Serial.println();
  
}

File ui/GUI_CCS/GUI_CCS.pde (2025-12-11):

/*
Uesed P5 elements:
Textfield  (set data)
Console (Println)

Slider (show measured data / set data)
Button

Tab (calibration / normal use)

Toggle (settings)



*/

//www.sojamo.de/libraries/controlp5
import controlP5.*;
ControlP5 cp5;

import processing.serial.*;
Serial myPort;      // The serial port


boolean showGraph = false;

int SLIDER_POS_X = 50;

int SLIDER_WIDTH = 200;
int SLIDER_HEIGHT = 30;

int SLIDER_DISTANCE = SLIDER_HEIGHT + 20;


void setup() 
{
  size(1000,400);
  noStroke();
  cp5 = new ControlP5(this);
  frameRate(20);  
  
  PFont pfont = createFont("Arial",20,true); // use true/false for smooth/no-smooth
  ControlFont font = new ControlFont(pfont,15);
  
  ///////////////////////////////////////////////////////////////////////////////
  /// Show Control
  cp5.addSlider("sliderCurrent")
     .setPosition(SLIDER_POS_X,50+0*SLIDER_DISTANCE)
     .setRange(0,2) //Range 2A (change by settings)
     .setCaptionLabel("[A]  Load Current") 
     .lock()
     .setSize(SLIDER_WIDTH, SLIDER_HEIGHT) 
     .setDecimalPrecision(3) 
     .setFont(font)
     ;
     
  cp5.addSlider("sliderVoltLoad")
     .setPosition(SLIDER_POS_X,1*SLIDER_DISTANCE + 50)
     .setRange(0,24)//Range 24V (change by settings)
     .setCaptionLabel("[V]  Load Voltage") 
     .lock()
     .setSize(SLIDER_WIDTH, SLIDER_HEIGHT) 
     .setDecimalPrecision(3) 
     .setFont(font)
     ;
     
  cp5.addSlider("sliderVoltExt")
     .setPosition(SLIDER_POS_X,2*SLIDER_DISTANCE + 50)
     .setRange(0,24)//Range 24V (change by settings)
     .setCaptionLabel("[V]  External Voltage") 
     .lock()
     .setSize(SLIDER_WIDTH, SLIDER_HEIGHT) 
     .setDecimalPrecision(3) 
     .setFont(font)
     ;
     
  cp5.addSlider("sliderTemp")
     .setPosition(SLIDER_POS_X,3*SLIDER_DISTANCE + 50)
     .setRange(0,200)//Range 24V (change by settings)
     .setCaptionLabel("[°C]  NTC Temp") 
     .lock()
     .setSize(SLIDER_WIDTH, SLIDER_HEIGHT) 
     .setDecimalPrecision(1) 
     .setFont(font)
     ;
     
  cp5.addSlider("sliderPower")
     .setPosition(SLIDER_POS_X,5*SLIDER_DISTANCE + 50)
     .setRange(0,2)//Range 2W (change by settings)
     .setCaptionLabel("[W]  Load Power") 
     .lock()
     .setSize(SLIDER_WIDTH, SLIDER_HEIGHT) 
     .setDecimalPrecision(3) 
     .setFont(font)
     ;
   ///////////////////////////////////////////////////////////////////////////////
   // Show Calibration / raw data
  cp5.addSlider("sliderRawCurrent")
     .setPosition(SLIDER_POS_X,50+0*SLIDER_DISTANCE)
     .setRange(0,32767)
     .setCaptionLabel("ADC  Load Current") 
     .lock()
     .setSize(SLIDER_WIDTH, SLIDER_HEIGHT) 
     .setDecimalPrecision(0) 
     .setFont(font)
     ;
     
  cp5.addSlider("sliderRawVoltLoad")
     .setPosition(SLIDER_POS_X,1*SLIDER_DISTANCE + 50)
     .setRange(0,32767)
     .setCaptionLabel("ADC  Load Voltage") 
     .lock()
     .setSize(SLIDER_WIDTH, SLIDER_HEIGHT) 
     .setDecimalPrecision(0) 
     .setFont(font)
     ;
     
  cp5.addSlider("sliderRawVoltExt")
     .setPosition(SLIDER_POS_X,2*SLIDER_DISTANCE + 50)
     .setRange(0,32767)
     .setCaptionLabel("ADC  External Voltage") 
     .lock()
     .setSize(SLIDER_WIDTH, SLIDER_HEIGHT) 
     .setDecimalPrecision(0) 
     .setFont(font)
     ;
     
  cp5.addSlider("sliderRawTemp")
     .setPosition(SLIDER_POS_X,3*SLIDER_DISTANCE + 50)
     .setRange(0,32767)
     .setCaptionLabel("ADC NTC") 
     .lock()
     .setSize(SLIDER_WIDTH, SLIDER_HEIGHT) 
     .setDecimalPrecision(0) 
     .setFont(font)
     ;
  ///////////////////////////////////////////////////////////////////////////////
  /// SET 
  
  cp5.addSlider("sliderSetCurrent")
     .setPosition(SLIDER_POS_X + SLIDER_WIDTH + 200 ,0*SLIDER_DISTANCE + 50)
     .setRange(0,10000) //10A - change range by setting TODO
     .setCaptionLabel("[mA] Load") 
     .setSize(SLIDER_WIDTH, SLIDER_HEIGHT) 
     .setDecimalPrecision(0) 
     .setScrollSensitivity(0.0025) //step=1
     .setFont(font)
     ; 
     
   cp5.addSlider("sliderSetBrightness")
     .setPosition(SLIDER_POS_X + SLIDER_WIDTH + 200 ,1*SLIDER_DISTANCE + 50)
     .setRange(0,100) //100%
     .setCaptionLabel("[%] Brightness") 
     .setSize(SLIDER_WIDTH, SLIDER_HEIGHT) 
     .setDecimalPrecision(0) 
     .setScrollSensitivity(0.1) //step=1
     .setFont(font)
     ; 

  cp5.addSlider("sliderSetRawDAC")
     .setPosition(SLIDER_POS_X + SLIDER_WIDTH + 200 ,0*SLIDER_DISTANCE + 50)
     .setRange(0,4095)
     .setCaptionLabel("DAC raw") 
     .setSize(SLIDER_WIDTH, SLIDER_HEIGHT) 
     .setDecimalPrecision(0) 
     .setScrollSensitivity(0.0025) //step=1
     .setFont(font)
     ; 

  ///////////////////////////////////////////////////////////////////////////////
  // create a new button
  cp5.addButton("BTNsetCurrent")
     .setValue(0)
     .setPosition(SLIDER_POS_X + SLIDER_WIDTH*3.2+100 ,0*SLIDER_DISTANCE + 50)
     .setSize(50,50)
     .setCaptionLabel("set") 
     .setFont(font)
     ;

   cp5.addButton("BTNsetBrightness")
     .setValue(0)
     .setPosition(SLIDER_POS_X + SLIDER_WIDTH*3.2+100 ,1.1*SLIDER_DISTANCE + 50)
     .setSize(50,50)
     .setCaptionLabel("set") 
     .setFont(font)
     ;    

  cp5.addButton("BTNsetDAC")
     .setValue(0)
     .setPosition(SLIDER_POS_X + SLIDER_WIDTH*3+100 ,0*SLIDER_DISTANCE + 50)
     .setSize(50,50)
     .setCaptionLabel("set") 
     .setFont(font)
     ;

     
  ///////////////////////////////////////////////////////////////////////////////
  /// init value
  cp5.getController("sliderCurrent").setValue(1.123); 
  
  ///////////////////////////////////////////////////////////////////////////////
  /// Tabs
  
  cp5.getTab("default")
     .activateEvent(true)
     .setLabel("Control")
     .setId(1)
     ;
  cp5.addTab("extra")
   .setColorBackground(color(0, 160, 100))
   .setColorLabel(color(255))
   .setColorActive(color(255,128,0))
   .setLabel("calibration")
   .setId(2)
   .activateEvent(true)
   ;
   
   
   cp5.getController("BTNsetDAC").moveTo("extra");
   cp5.getController("sliderSetRawDAC").moveTo("extra");
   
   cp5.getController("sliderRawCurrent").moveTo("extra");
   cp5.getController("sliderRawVoltLoad").moveTo("extra");
   cp5.getController("sliderRawVoltExt").moveTo("extra");
   cp5.getController("sliderRawTemp").moveTo("extra");
   
   
   

   
  
  ///////////////////////////////////////////////////////////////////////////////
  /// serial
  printArray(Serial.list());
  
  
  String portName = Serial.list()[0];
  myPort = new Serial(this, portName, 115200);
  
  
}

int offsetX = 50;
int offsetY = 300;

int timeX = 0;
/*
void draw() 
{
  //background(100);
  stroke(255);
  
  point(50,200);
  
  
  float tY = cp5.getController("sliderTemp").getValue();
  line(offsetX+timeX, 400-tY, offsetX+timeX, 400);
}
*/


int width = 800;                                                   //use this variable to controll screen widtt
int height = 400;                                                  //use this variable to controll screen height
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

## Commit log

2022-10-25 add aisler link to order PCB
2025-12-11 add load power calculation to UI
2025-12-11 add brightness slider, apply gamma correction mith 700mA max
    [GUI_CCS.pde]
2025-12-11 send current value when brightness slider is changed
